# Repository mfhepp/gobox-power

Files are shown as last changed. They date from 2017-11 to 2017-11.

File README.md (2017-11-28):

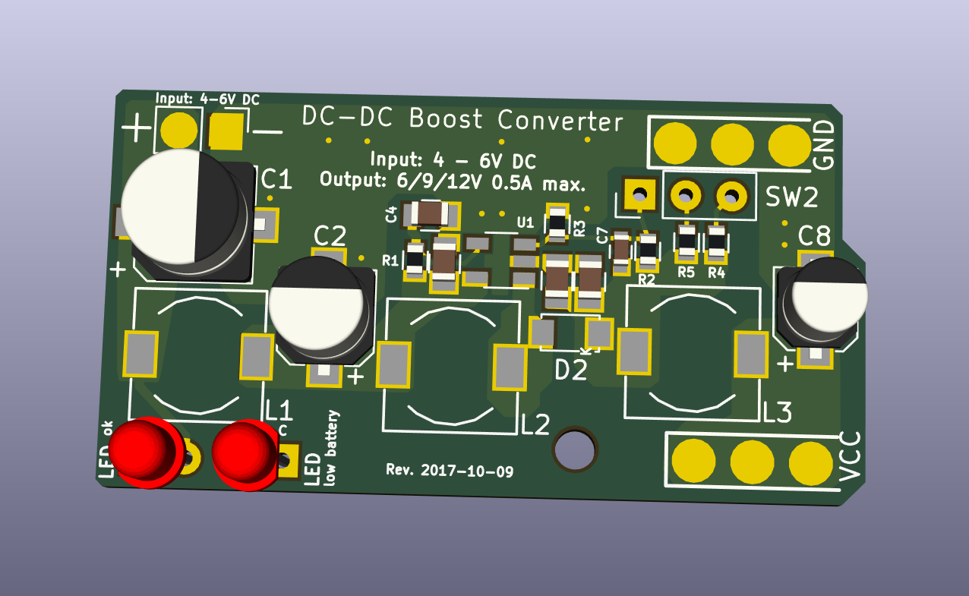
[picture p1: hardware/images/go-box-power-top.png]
DC-DC Boost Converter with Input and Output Filter


**Note:** This is work-in-progress. I will remove this message when the materials are ready for use.

# DC-DC Boost Converter with Input and Output Filter for QRP Transceivers
This project contains the necessary files and assembly instructions for a small PCB that includes a
a) DC-DC boost converter with effective input and output filters and a
b) battery voltage indicator circuit.

The board was designed for the [Mountain Topper SOTA GoBox](https://github.com/mfhepp/gobox) project, but can be used for any other similar project.

The boost converter is carefully designed to minimize RF emissions and noise on the output and output so that it does not impact the reception of weak radio signals in amateur radio transceivers. 

## Use with 4 NimH Cells ##
In the current form, the circuit will generate 6, 9 or 12 V from a 4 - 6 V input source, like four AA-sized NiMH batteries. This will give roughly 1 , 2.5 and 5 W output power with a Mountain Topper transceiver.

## Use with 2S Lipo Batteries ##
By modifying R4 and R5 one can also produce other voltages. The design can also be used with two LiPo cells, but then a simple SPST switch should be used for SW1 so that it optionally connects R5 parallel to R2. R4 can be omitted in this case, and only 9 or 12 V will be selectable.

You will also have to replace the Zener diode D3 to a type with Zener voltage of ca. 6.2 V so that the low battery warning will use the proper voltages for LiPos (see below).

## Input Current ##
The input current must not exceed 1.4 A, and the input voltage must be lower or equal to the lowest output voltage.

The input current is roughly the output current times the ratio of output voltage to input voltage plus the losses as the inverse of the efficiency (80 - 90%).

`input_current = output_current * output_voltage / (input_voltage * 0.85)`

**You also have to make sure that the battery used can handle the peak input current!!!** Check the datasheet of the battery before usage.

Design decisions will also be included in the final version.

## Low Battery Warning ##
The circuit includes a low battery warning component, but it is up to the user to actually turn of the circuit. As the battery voltages decreases, the red LED ("LOW1") wil start to light, and the green LED ("PWR1") will dim and eventually go out completely.

The exact voltage is determined by the Zener diode D3. For NiMH batteries with four cells, use a 3.9V type. For 2S LiPo packs, a 6.2V Zener diode might be a good choice.

**Warning 1:** You should turn off the device as soon as the green LED goes out completely, and switch back to the lower output voltages (6 or 9V) as soon as the red LED starts lighting. Otherwise, you will likely harm your battery, and because of the increasing input current needed to maintain the fixed output voltage, the circuit may overheat.

**Warning 2:** The battery voltage indicator does only consider the total series voltage of all battery cells. If there is an imbalance due to one or more cells being aged or damaged, the low battery warning will come too late. Thus, use the circuit only with factory-assembled multi-cell packs.

## Overview 
tbd

## Circuit Description 
tbd

## Ripple and Noice ##

Below, please find measurements of the remaining ripple and noise. The output voltage shows practically no ripple (less than 12mV Peak-to-Peak), the input voltage very little (ca. 66 mV Peak-to-Peak).

The parameters of the measurement were as follows:<br />
Input voltage: 9V from a 9V block battery.<br />
Load: 100 R resistor<br />
Output voltage: 11.9V<br />
Output current: 119 mA <br />

Measurements taken with a DMM and a Rigol Oscilloskope with a 1.10 probe.

**Input Voltage Ripple and Noise:** <br />
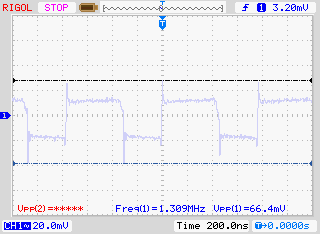
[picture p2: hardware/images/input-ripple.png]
Input Voltage Ripple


**Output Voltage Ripple and Noise:** <br />
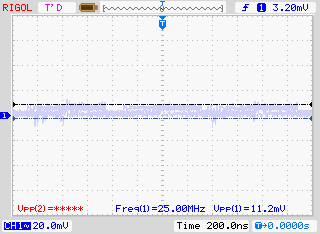
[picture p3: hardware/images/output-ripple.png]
Output Voltage Ripple


## Part List
An Excel file that can be uploaded to Mouser's BOM tool is included in the repository at

https://github.com/mfhepp/gobox-power/raw/master/hardware/go-box-power.xlsx

## Assembly
**Note:** This is a densely packed PCB design using SMD components in size 0603, and for minimizing EMI, the pads do not have thermal relief, i.e. are directly connected to the copper of the ground signal and other signals. This makes soldering a bit challenging, and reworking even more so. In other words, this should not be your first exercise in SMD soldering....

The components are placed with minimal distances, so when hand-soldering, you need to think carefull about the ordering of components. Some pads will become hard to reach for hand-soldering once the adjacent component will have been added.

Because of the lack of thermal relief and the pads, you need to use a higher soldering temperature (I found 400 °C to work well), but this in turn means you have to work swiftly. I recommend a flat 1.2mm tip and a round 0.4 mm tip for the work. Preheating the PCB might be a good idea. You also need the finest rosin-core solder you can get hold of.

## Sources
The files in the repository contain 
* Gerber and drill files for producing your own PCBs, and
* a KiCad project with the schematics, PCB, and parts and footprints libraries.

KiCad is a great and free electronics design package. For more information, see [http://kicad-pcb.org/](http://kicad-pcb.org/).

## Acknowledgments
tbd

## Disclaimer 
THE SOFTWARE AND DESIGN ARE PROVIDED "AS IS", WITHOUT WARRANTY OF ANY KIND, EXPRESS OR IMPLIED, INCLUDING BUT NOT LIMITED TO THE WARRANTIES OF MERCHANTABILITY, FITNESS FOR A PARTICULAR PURPOSE AND NONINFRINGEMENT. IN NO EVENT SHALL THE AUTHORS OR COPYRIGHT HOLDERS BE LIABLE FOR ANY CLAIM, DAMAGES OR OTHER LIABILITY, WHETHER IN AN ACTION OF CONTRACT, TORT OR OTHERWISE, ARISING FROM, OUT OF OR IN CONNECTION WITH THE SOFTWARE OR DESIGN OR THE USE OR OTHER DEALINGS IN THE SOFTWARE OR DESIGN.

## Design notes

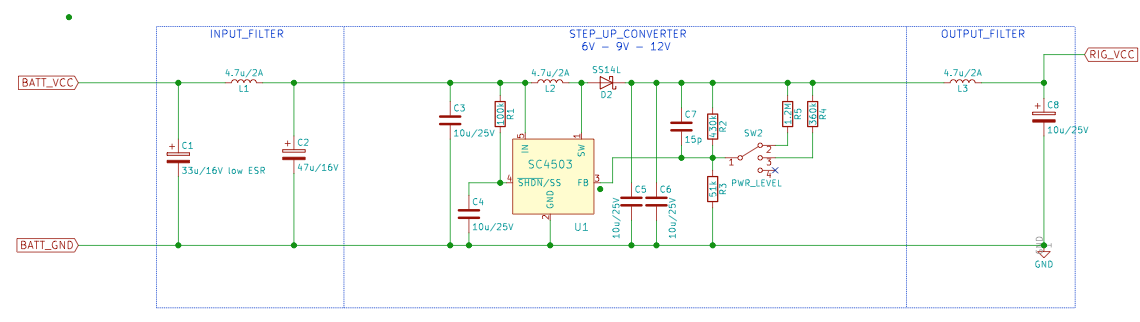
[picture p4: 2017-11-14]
hardware/images/schematic.png

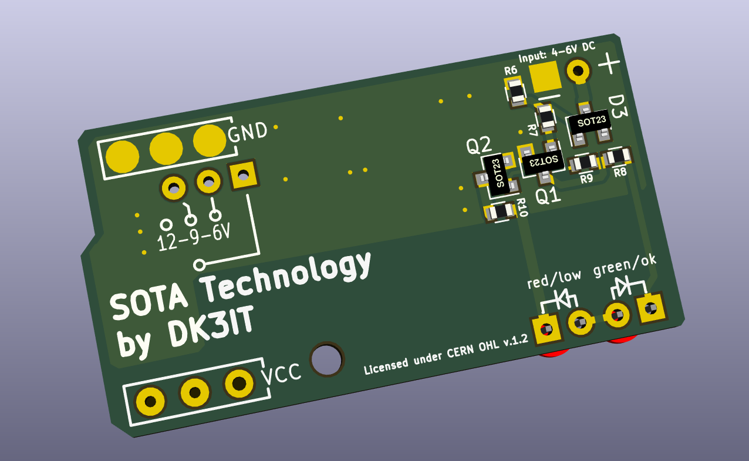
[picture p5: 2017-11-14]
hardware/images/go-box-power-bottom.png

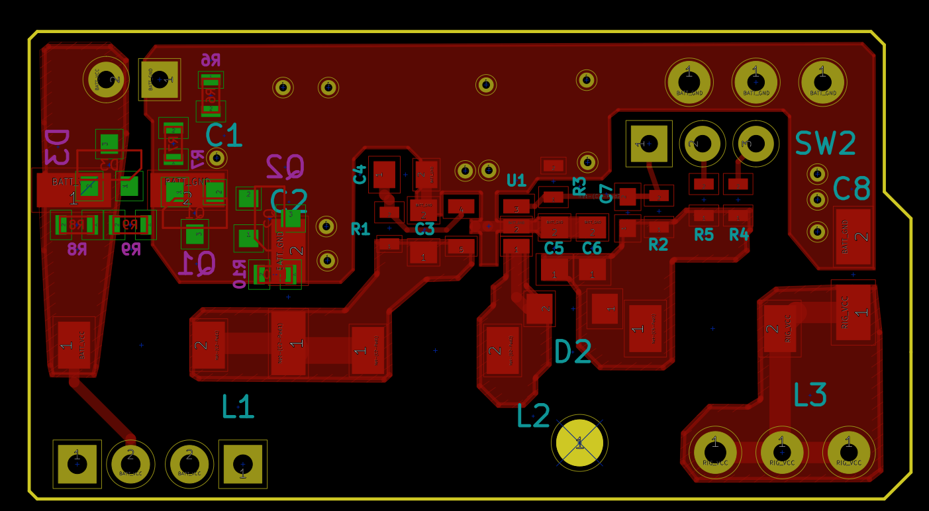
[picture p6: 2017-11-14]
hardware/images/top-layer.png

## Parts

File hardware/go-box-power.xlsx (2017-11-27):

ref | qtty | value | footprint | MFN | MPN | Mouser Part Number | Mouser Part Link | Alternative Source Name | Alternative Source Part Number | Characteristics | Description | Package ID | Source | Critical | Notes | Fieldname | Design Decision URI
BT1 | 1 | 4.8V 4-cell NiMH Battery | mfhepp:not_on_board | n/a | n/a | n/a | n/a | n/a | n/a | n/a | n/a | n/a | ANY | N | n/a | Value
C1 | 1 | 33u/16V low ESR | Capacitors_SMD:CP_Elec_6.3x5.3 | Würth | 865080343005 | 710-865080343005 | http://www.mouser.de/ProductDetail/Wurth-Electronics/865080343005/ | n/a | n/a | n/a | n/a | n/a | ANY | Y | n/a | Value
C2 | 1 | 47u/16V | Capacitors_SMD:CP_Elec_5x5.8 | Panasonic | EEE-FK1C470UR | 667-EEE-FK1C470UR | http://www.mouser.de/ProductDetail/Panasonic/EEE-FK1C470UR/ | n/a | n/a | 47u / 16 V /& ESR = 700mOhm | n/a | n/a | ANY | Y | ESR ca. 700mOhm | Value
C5, C6, C3, C4 | 4 | 10u/25V | Capacitors_SMD:C_0805 | Murata | GRM21BZ71E106KE15L | 81-GRM21BZ71E106KE5L | http://www.mouser.de/ProductDetail/Murata-Electronics/GRM21BZ71E106KE15L/ | n/a | n/a | n/a | n/a | 0805 | ANY | Y | n/a | Value
C7 | 1 | 15p | Capacitors_SMD:C_0603 | Murata | GCM1885C1H150JA16D | 81-GCM1885C1H150J16D | https://www.mouser.de/ProductDetail/Murata-Electronics/GCM1885C1H150JA16D/ | n/a | n/a | C0G (NP0) | 15pF/50V | n/a | ANY | N | n/a | Value | n/a
C8 | 1 | 10u/25V | Capacitors_SMD:CP_Elec_4x5.8 | Panasonic | EEE-FP1E100AR | 667-EEE-FP1E100AR | http://www.mouser.de/ProductDetail/Panasonic/EEE-FP1E100AR/ | n/a | n/a | n/a | n/a | n/a | ANY | Y | ESR low but not too low | Value
CHARGE1 | 1 | 2.5MM | mfhepp:not_on_board | Lumberg | NEB/J 25 C | n/a | n/a | Reichelt | n/a | Isolated, with switch | n/a | n/a | ANY | Y | https://www.reichelt.de/index.html?ACTION=3;ARTICLE=116256;SEARCH=LUM%20NEBJ%2025C | Value
D1 | 1 | 1N5822 | mfhepp:not_on_board | STMicroelectronics | 1N5822RL | 511-1N5822-TR | http://www.mouser.de/ProductDetail/STMicroelectronics/1N5822RL/ | n/a | n/a | 40V/3A | Schottky Diodes & Rectifiers Vr/40V Io/3A T/R | n/a | ANY | N | n/a | Value
D2 | 1 | SS14L | mfhepp:D_SubSMA | Taiwan Semiconductor | SS14L | 821-SS14L | http://www.mouser.de/ProductDetail/Taiwan-Semiconductor/SS14L/ | n/a | n/a | n/a | Schottky Diodes & Rectifiers 1A 40V | n/a | ANY | Y | n/a | Value
D3 | 1 | BZX84-3.9V | TO_SOT_Packages_SMD:SOT-23 | ON Semiconductor | BZX84C3V9LT1G | 863-BZX84C3V9LT1G | http://www.mouser.de/ProductDetail/ON-Semiconductor/BZX84C3V9LT1G/ | n/a | n/a | n/a | Zener Diodes 3.9V 225mW | SOT-23-3 | ANY | N | n/a | Value
EXT_BATTERY1 | 1 | 2.1MM | mfhepp:not_on_board | Lumberg | NEB/J 21 C | n/a | n/a | Reichelt | n/a | Isolated, with switch | n/a | n/a | ANY | Y | n/a | Value
F1 | 1 | Polyfuse 1.85/3A | mfhepp:not_on_board | Littelfuse | 30R185UPR | 576-30R185UPR | http://www.mouser.de/ProductDetail/Littelfuse/30R185UPR/ | Reichelt | PFRA 185 | n/a | n/a | n/a | ANY | Y | n/a | Value
J1 | 1 | DC_JACK | mfhepp:Generic_2-Pin_Connector_0.8mm | n/a | n/a | n/a | n/a | n/a | n/a | n/a | n/a | n/a | ANY | N | n/a | Value
J2 | 1 | RIG_VCC | Wire_Pads:SolderWirePad_3x_0-8mmDrill | n/a | n/a | n/a | n/a | n/a | n/a | n/a | n/a | n/a | ANY | N | n/a | Value
J3 | 1 | RIG_GND | Wire_Pads:SolderWirePad_3x_0-8mmDrill | n/a | n/a | n/a | n/a | n/a | n/a | n/a | n/a | n/a | ANY | N | n/a | Value
L1, L3, L2 | 3 | 4.7u/2A | Choke_SMD:Choke_SMD_7.3x7.3_H4.5 | TDK | B82472G6472M000 | 871-B82472G6472M000 | http://www.mouser.de/ProductDetail/EPCOS-TDK/B82472G6472M000/ | n/a | n/a | n/a | n/a | n/a | ANY | N | n/a | Value
LOW1 | 1 | red | lib_fr:LED_D3.0mm-external | Kingbright | WP710A10IT | 604-WP710A10IT | http://www.mouser.de/ProductDetail/Kingbright/WP710A10IT/ | n/a | n/a | n/a | LED 3mm red | n/a | ANY | N | n/a | Value
PWR1 | 1 | green | lib_fr:LED_D3.0mm-external | Kingbright | WP710A10GD | 604-WP710A10GD | http://www.mouser.de/ProductDetail/Kingbright/WP710A10GD/ | n/a | n/a | n/a | LED 3mm green | n/a | ANY | N | n/a | Value
Q1, Q2 | 2 | BC847 | TO_SOT_Packages_SMD:SOT-23 | ON Semiconductor | BC847ALT1G | 863-BC847ALT1G | http://www.mouser.de/ProductDetail/ON-Semiconductor/BC847ALT1G/ | n/a | n/a | n/a | Bipolar Transistors - BJT 100mA 50V NPN | SOT-23-3 | ANY | N | n/a | Value
R1 | 1 | 100k | Resistors_SMD:R_0603 | Vishay | CRCW0603100KFKEA | 71-CRCW0603-100K-E3 | http://www.mouser.com/ds/2/427/dcrcwe3-109170.pdf | n/a | n/a | n/a | Resistor SMD 1/10W 100Kohm 1% or better | n/a | ANY | N | n/a | Value
R2 | 1 | 430k | Resistors_SMD:R_0603 | Vishay | CRCW0603430KFKEA | 71-CRCW0603-430K-E3 | http://www.mouser.de/ProductDetail/Vishay/CRCW0603430KFKEA/ | n/a | n/a | n/a | 430k / 1 % or better | n/a | ANY | N | n/a | Value
R3 | 1 | 51k | Resistors_SMD:R_0603 | Vishay | CRCW060351K0FKEA | 71-CRCW0603-51K-E3 | http://www.mouser.de/ProductDetail/Vishay/CRCW060351K0FKEA/ | n/a | n/a | n/a | n/a | n/a | ANY | N | n/a | Value
R4 | 1 | 360k | Resistors_SMD:R_0603 | Vishay | CRCW0603360KFKEA | 71-CRCW0603360KFKEA | http://www.mouser.de/ProductDetail/Vishay/CRCW0603360KFKEA/ | n/a | n/a | 1% 100 mW | n/a | n/a | ANY | N | n/a | Value
R5 | 1 | 1.2M | Resistors_SMD:R_0603 | Vishay | CRCW06031M20FKEA | 71-CRCW06031M20FKEA | http://www.mouser.de/ProductDetail/Vishay/CRCW06031M20FKEA/ | n/a | n/a | 1% | n/a | n/a | ANY | N | n/a | Value
R6 | 1 | 1k | Resistors_SMD:R_0603 | Vishay | CRCW06031K00FKEB | 71-CRCW06031K00FKEB | http://www.mouser.de/ProductDetail/Vishay/CRCW06031K00FKEB/ | n/a | n/a | n/a | Resistor SMD 1/10W 1 kOhm | n/a | ANY | N | n/a | Value
R7 | 1 | 10k | Resistors_SMD:R_0603 | Vishay | CRCW060310K0FKEA | 71-CRCW0603-10K-E3 | http://www.mouser.de/ProductDetail/Vishay/CRCW060310K0FKEA/ | n/a | n/a | n/a | Resistor SMD 1/10W 10Kohm | n/a | ANY | N | n/a | Value
R8, R10 | 2 | 220 | Resistors_SMD:R_0603 | Vishay | CRCW0603220RFKEA | 71-CRCW0603-220-E3 | http://www.mouser.de/ProductDetail/Vishay/CRCW0603220RFKEA/ | n/a | n/a | n/a | Resistor SMD 1/10W 220 Ohm | n/a | ANY | N | n/a | Value
R9 | 1 | 47k | Resistors_SMD:R_0603 | Vishay | CRCW060347K0FKEA | 71-CRCW0603-47K-E3 | http://www.mouser.de/ProductDetail/Vishay/CRCW060347K0FKEA/ | n/a | n/a | n/a | Resistor SMD 1/10W 47Kohm | n/a | ANY | N | n/a | Value
SW1 | 1 | ON | mfhepp:not_on_board | Miyama | MS-165 | n/a | n/a | Reichelt | MS 165 | n/a | Toggle switch, 1-pin, 10 A - 125 V AC, on-off | n/a | ANY | N | n/a | Value
SW2 | 1 | PWR_LEVEL | mfhepp:SW2-3pins | Miyama | MS-167 | n/a | n/a | Reichelt | MS 167 | n/a | n/a | n/a | ANY | N | n/a | Value
U1 | 1 | SC4503 | TO_SOT_Packages_SMD:TSOT-23-5 | Semtech | SC4503TSKTRT | 947-SC4503TSKTRT | http://www.mouser.de/ProductDetail/Semtech/SC4503TSKTRT/ | n/a | n/a | n/a | Switching Voltage Regulators 1.3MHZ STEP-UP SW REG W 1.4A | TSOT-23-5 | ANY | Y | n/a | Value

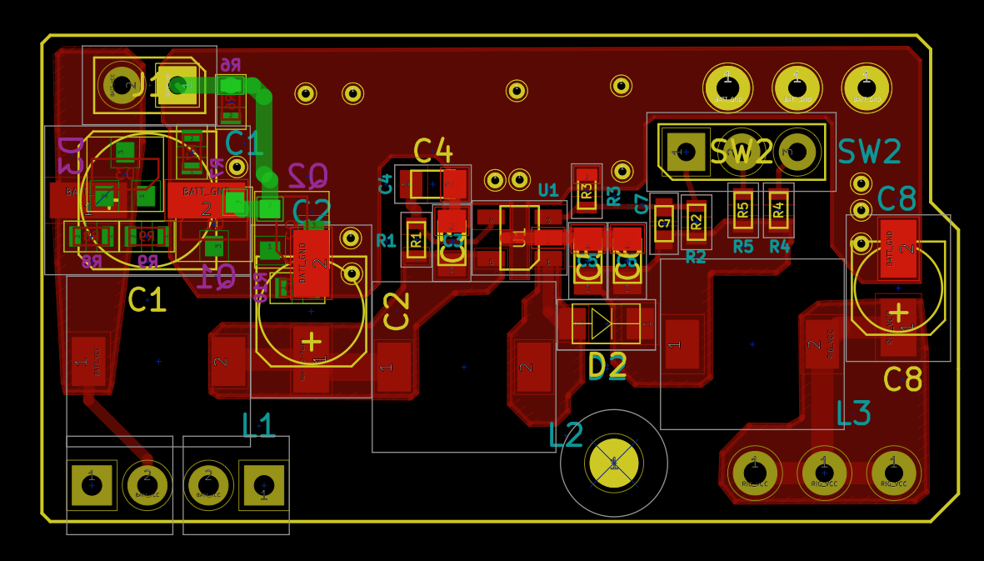
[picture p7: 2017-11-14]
hardware/images/top-layer-with-components.png

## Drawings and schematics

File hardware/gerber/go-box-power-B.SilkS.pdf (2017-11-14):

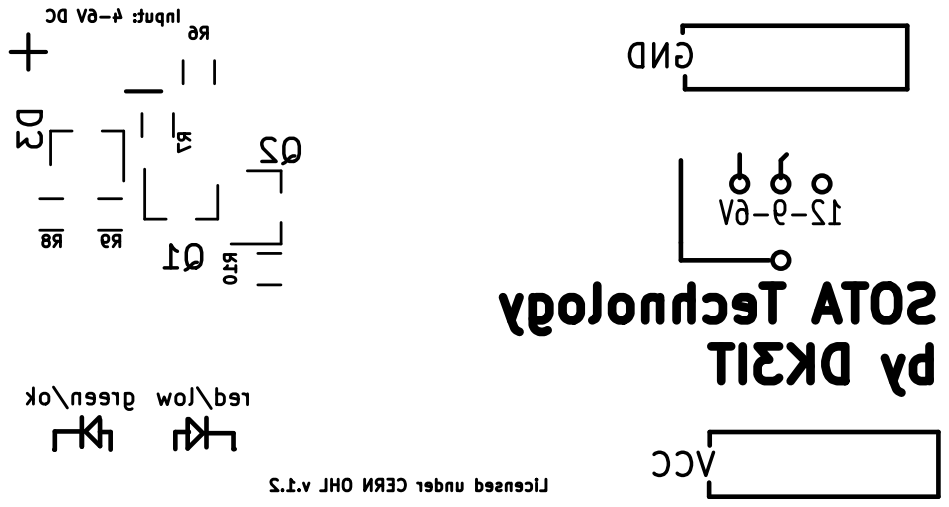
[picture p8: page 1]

Licensed under CERN OHL v.1.2 - +

green/ok red/low 12-9-6V SOTA Technology

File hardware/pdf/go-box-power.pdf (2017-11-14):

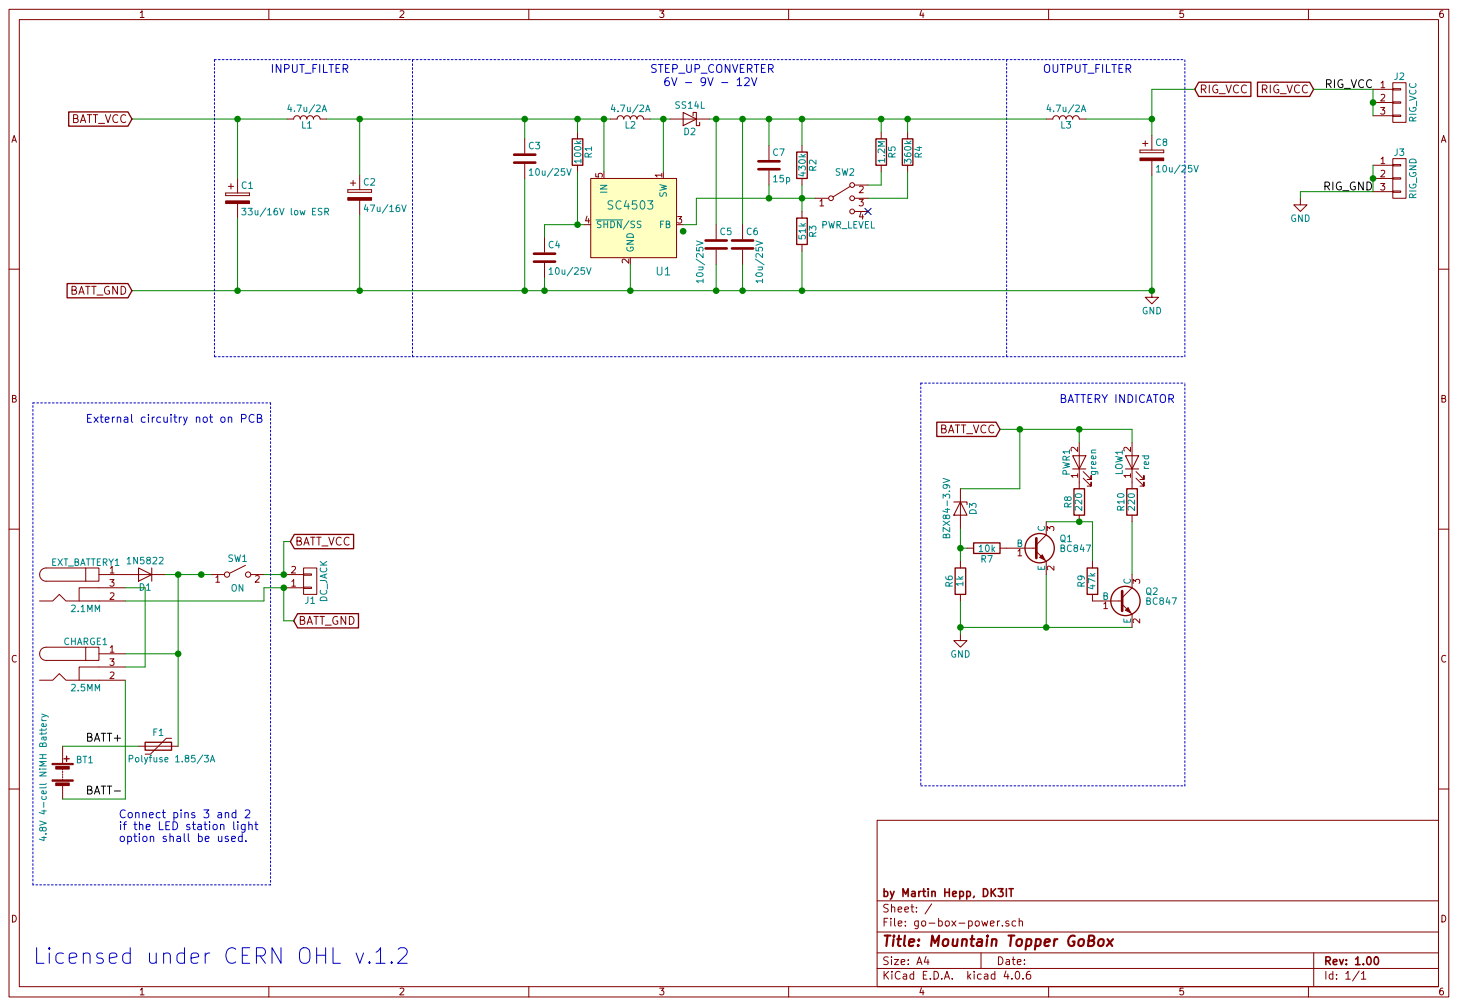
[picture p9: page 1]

GND RIG_GND C2
BATT+ BATT- External circuitry not on PCB

2 FB 3 SHDN/SS 4 IN

if the LED station light
option shall be used.

File: go-box-power.sch Sheet: / by Martin Hepp, DK3IT

Licensed under CERN OHL v.1.2

Id: 1/1 Title: Mountain Topper GoBox

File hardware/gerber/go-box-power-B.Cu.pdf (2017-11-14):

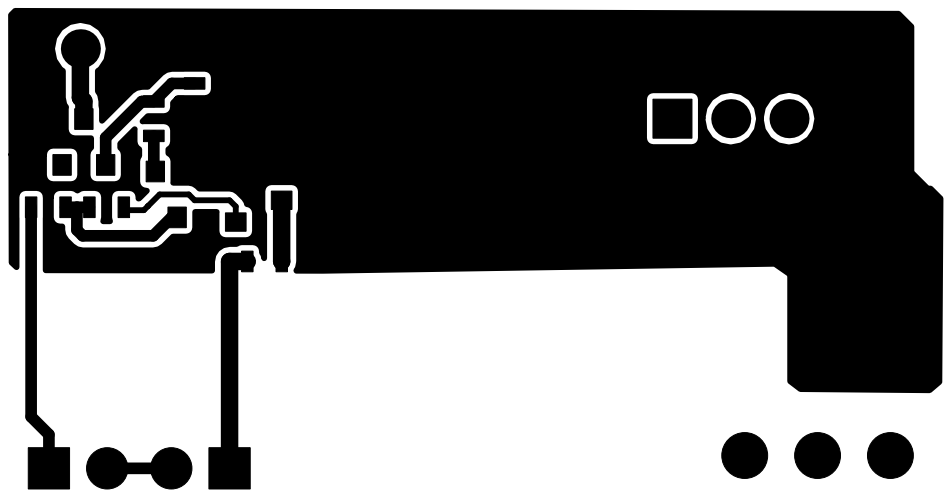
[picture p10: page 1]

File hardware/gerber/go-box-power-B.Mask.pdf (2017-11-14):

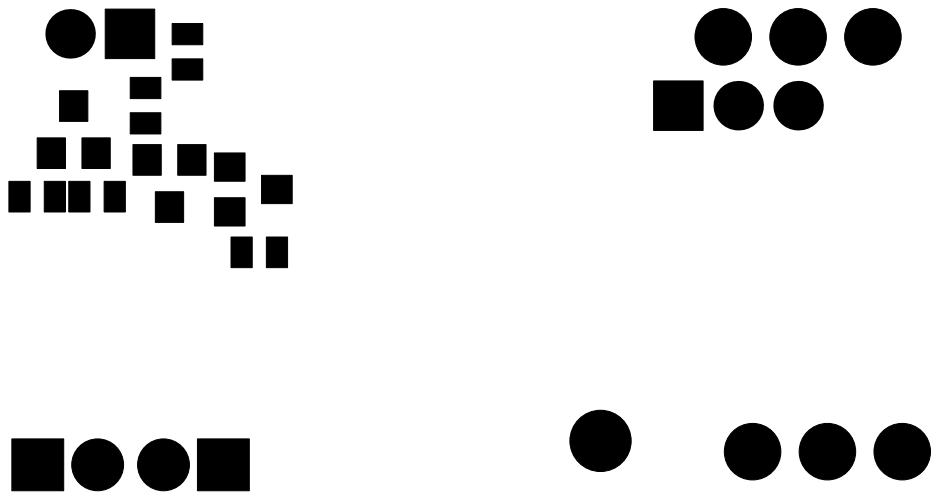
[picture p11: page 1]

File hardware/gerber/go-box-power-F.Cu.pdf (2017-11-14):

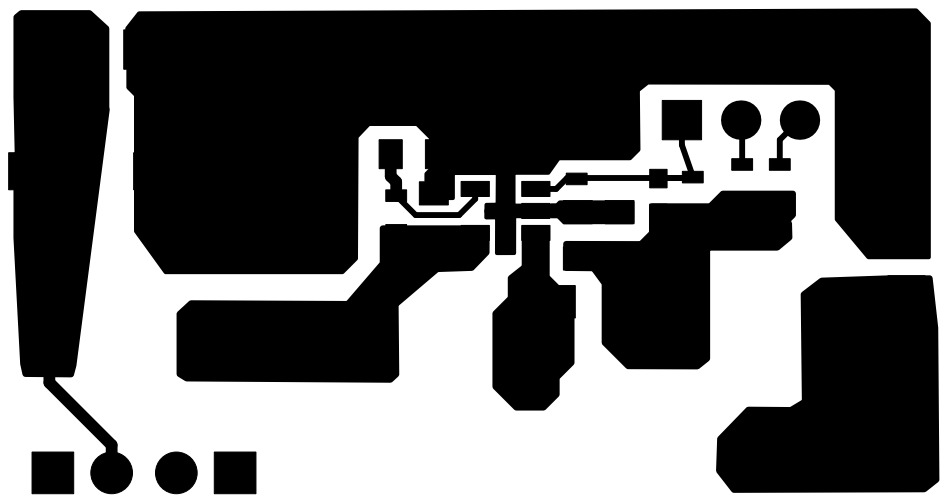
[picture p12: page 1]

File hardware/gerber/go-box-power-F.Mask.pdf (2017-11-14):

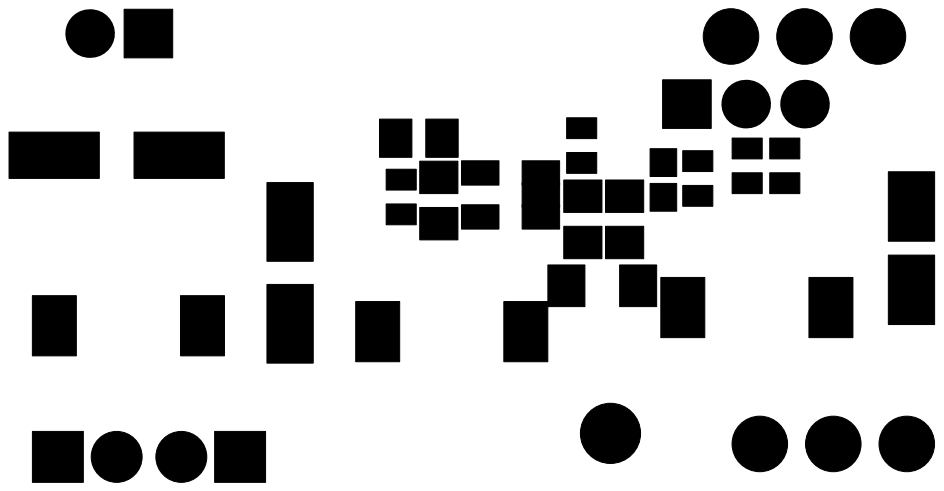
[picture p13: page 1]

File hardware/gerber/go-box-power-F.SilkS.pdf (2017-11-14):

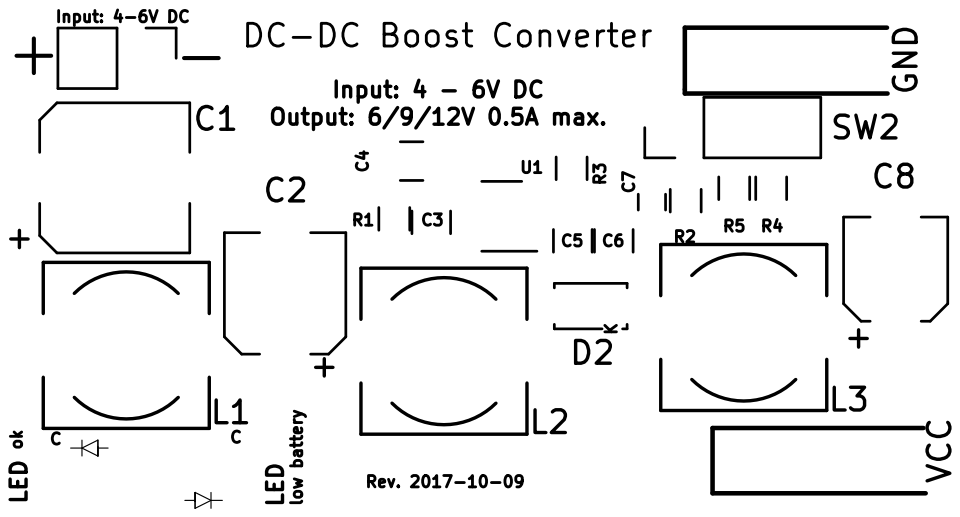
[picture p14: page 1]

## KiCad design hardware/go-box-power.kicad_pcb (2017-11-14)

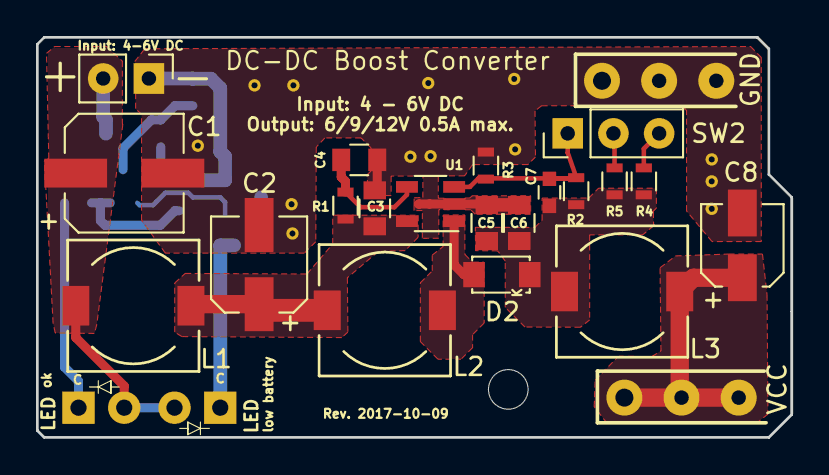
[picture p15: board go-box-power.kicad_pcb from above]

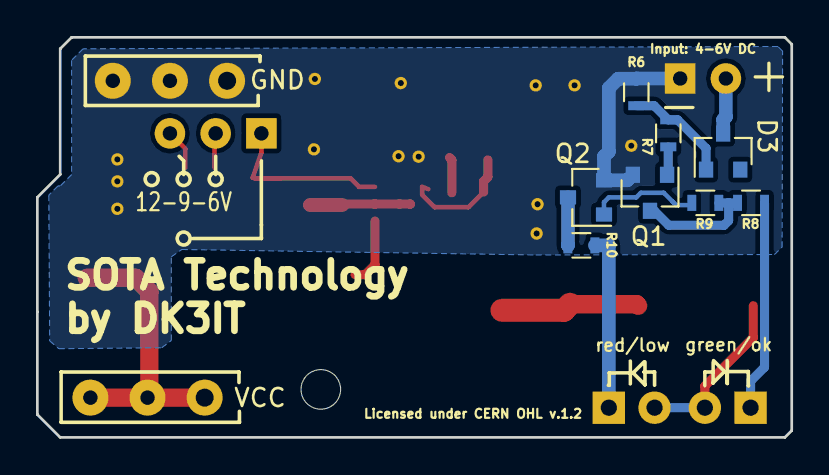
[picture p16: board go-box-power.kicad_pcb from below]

Board: 2 copper layers, 41.9 x 22.2 mm, 38 parts (8 on the bottom side), 17 nets.

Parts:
BT1: 4.8V 4-cell NiMH Battery; not_on_board
C1: 33u/16V low ESR; CP_Elec_6.3x5.3
C2: 47u/16V; CP_Elec_5x5.8
C3, C4, C5, C6: 10u/25V; C_0805
C7: 15p; C_0603
C8: 10u/25V; CP_Elec_4x5.8
CHARGE1: 2.5MM; not_on_board
D1: 1N5822; not_on_board
D2: SS14L; D_SubSMA
D3: BZX84-3.9V; SOT-23
EXT_BATTERY1: 2.1MM; not_on_board
F1: Polyfuse 1.85/3A; not_on_board
J1: DC_JACK; Generic_2-Pin_Connector_0.8mm
J2: RIG_VCC; SolderWirePad_3x_0-8mmDrill
J3: RIG_GND; SolderWirePad_3x_0-8mmDrill
L1, L2, L3: 4.7u/2A; Choke_SMD_7.3x7.3_H4.5
LOW1: red; LED_D3.0mm-external
PWR1: green; LED_D3.0mm-external
Q1, Q2: BC847; SOT-23
R1: 100k; R_0603
R2: 430k; R_0603
R3: 51k; R_0603
R4: 360k; R_0603
R5: 1.2M; R_0603
R6: 1k; R_0603
R7: 10k; R_0603
R8, R10: 220; R_0603
R9: 47k; R_0603
SW1: ON; not_on_board
SW2: PWR_LEVEL; SW2-3pins
U1: SC4503; TSOT-23-5

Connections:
BATT_GND: C1.2, C2.2, C3.2, C4.2, C5.2, C6.2, C8.2, J1.1, J3.1, Q1.2, Q2.2, R3.2, R6.1, U1.2
BATT_VCC: C1.1, D3.3, J1.2, L1.1, LOW1.2, PWR1.2
unnamed: C2.1, C3.1, L1.2, L2.1, R1.1, U1.5
unnamed: C4.1, R1.2, U1.4
unnamed: C5.1, C6.1, C7.1, D2.1, L3.1, R2.1, R4.1, R5.1
unnamed: C7.2, R2.2, R3.1, SW2.1, U1.3
unnamed: D2.2, L2.2, U1.1
unnamed: D3.1, R6.2, R7.2
unnamed: LOW1.1, R10.2
unnamed: PWR1.1, R8.2
unnamed: Q1.1, R7.1
unnamed: Q1.3, R8.1, R9.2
unnamed: Q2.1, R9.1
unnamed: Q2.3, R10.1
unnamed: R4.2, SW2.3
unnamed: R5.2, SW2.2
RIG_VCC: C8.1, J2.1, L3.2

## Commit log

2017-11-14 initial version
    [go-box-power-B.Cu.gbl, go-box-power-B.Mask.gbs, go-box-power-B.SilkS.gbo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]
2017-11-27 fixed C7 footprint; README.md, measurements
    [go-box-power.sch, go-box-power.xlsx]
